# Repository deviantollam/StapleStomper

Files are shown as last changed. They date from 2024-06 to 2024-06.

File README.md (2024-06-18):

# Staple and Flag Tool

This tool was designed for ToorCamp to facilitate ShadyTel staff and other volunteers placing and removing landscaping staples and flags without throwing out their back!

## Features
- Magnetic Landscaping Staple Holder
  - Compatible with 2mm / 13 AWG / 14 AWG thickness, less than 32mm wide staples.
- Staple Removal Hook
- Landscaping Flag Holder (magnetic and friction fit)
- Landscaping Flag Removal Tool

## Changelog:

2024-06-18: Initial Release

## Bill of Materials:

- Approximately 20m of PETG filament
- 2x 6*10 mm round neodymium magnets 
- 3x 6*2 mm round neodymium magnets
- Cyanoacrylate glue or similar for setting magnets

- 1x 1/2" wooden dowel, cut to length
- 3 to 10 screws, depending on what you have on hand. 
  - #6 x 3/4" drywall screws preferred, M4 screws also compatible
  - (optional) a drill and drill bit to prevent the dowel from splitting
- (optional) Rubber Bands

## Print Instructions

### Staple Stomper

**Quantity Needed: 1**

The part should be oriented such that the hole for the dowel is pointed upwards / text is upright.

Supports are likely needed for under the circular feature for the dowel. I would recommend NOT adding supports into the magnet or staple holes unless you know you need them and can remove them cleanly.

Print in PETG, ASA, ABS, PC, or other material suited for impact resistance and direct sunlight at a minimum of 20% infill.

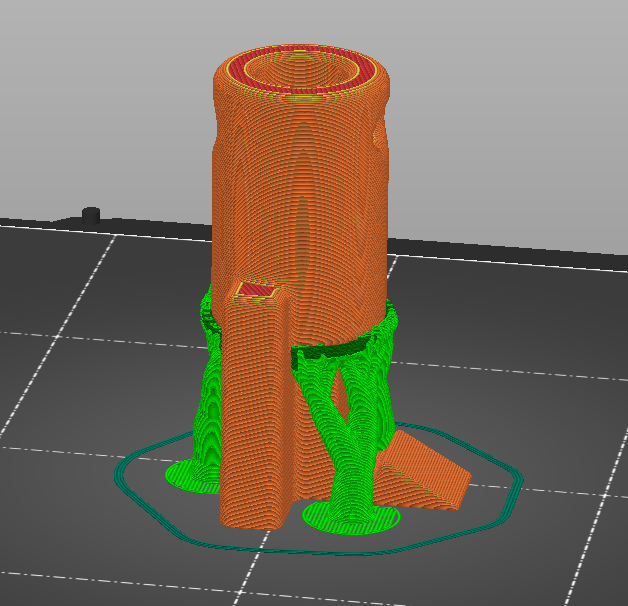
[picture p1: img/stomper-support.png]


### Flagpole Cap

**Quantity Needed: 1**

The part should be oriented so that it prints on its tallest axis. It will print better if the serrated feature faces up. No supports should be needed. 

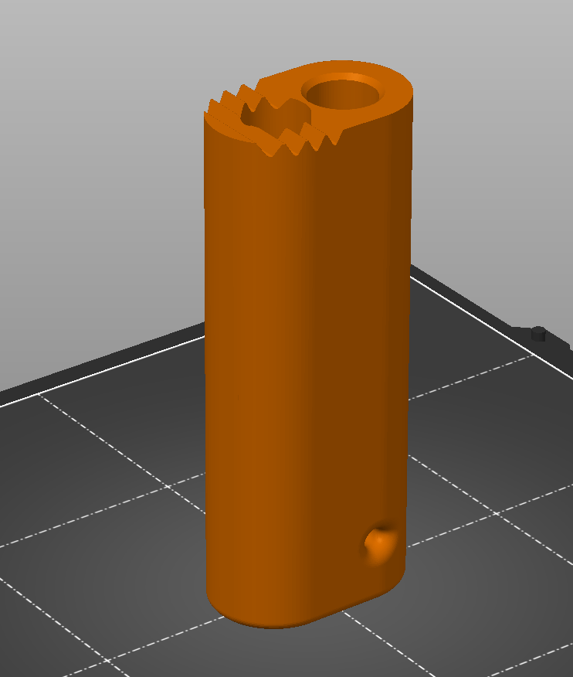
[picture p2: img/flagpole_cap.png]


Print in PETG, ASA, ABS, PC, or other material suited for impact resistance and direct sunlight at a minimum of 20% infill.

### Flagpole Guide

**Quantity Needed: 1 or 2**

The part should be oriented so that it prints on of the two flat faces. It will print better if the serrated feature faces up. No supports should be needed. 

Only 1 piece should be needed, but if you have especially long flags or if the soil is very hard, you may print an additional guide to help with flag placement.

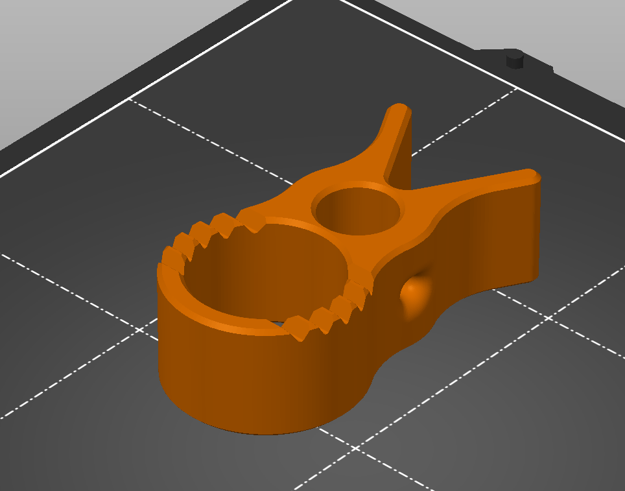
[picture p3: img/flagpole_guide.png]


Print in PETG, ASA, ABS, PC, or other material suited for impact resistance and direct sunlight at a minimum of 20% infill.

## Assembly Instructions

### Glue-Up

For the Staple Stomper, glue 1x 6 x 2mm magnet in the bottom for holding onto staples as you pull them from the ground.

Glue or place 1x 6 x 10 mm magnet in the dowel hole. When a dowel is installed, it will hold the magnet in if you do not wish to glue it.

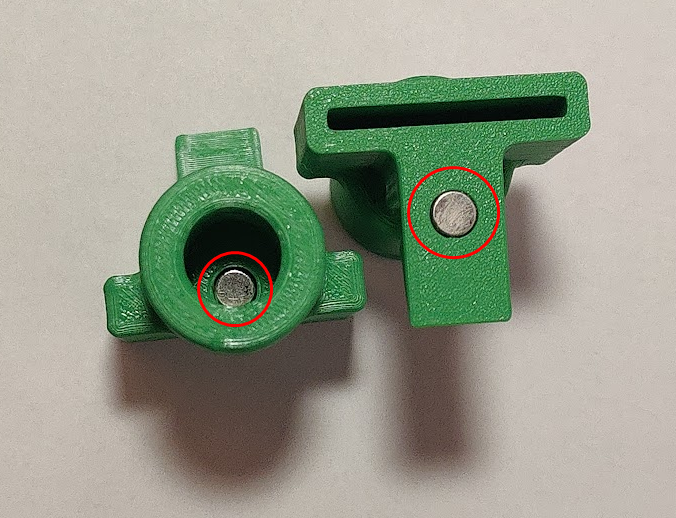
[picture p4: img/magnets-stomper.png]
img magnets


For the Flagpole Cap, glue 1x 6 x 10mm in the small diagonal hole on the top of the cap.

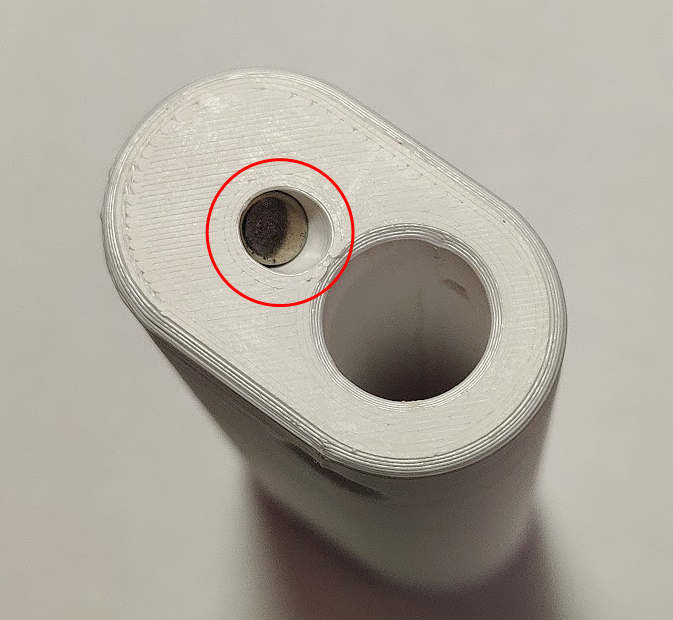
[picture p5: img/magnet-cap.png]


For the Flagpole Guide(s), glue 2x 6 x 2mm magnets in the two circular holes within the V. 

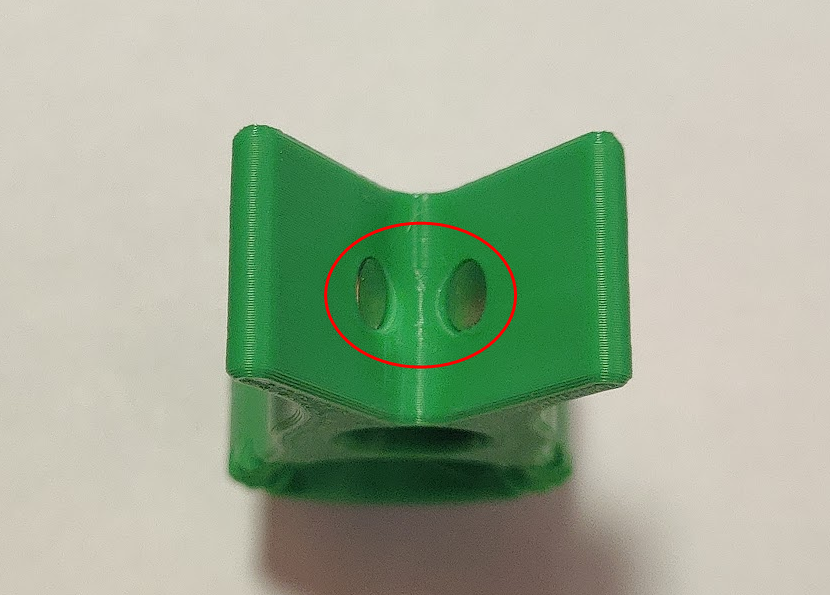
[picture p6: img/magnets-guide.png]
img magnets


### Screw-Up

1. Cut the dowel to a comfortable or convenient length for you.

2. Screw the Staple Stomper onto one end of the dowel. Pre-drill the hole if you need to. Don't forget to include the magnet if you wish to include it!

3. Insert a flag into the flag cap. Slide the flag cap on the other end of the dowel, such that the flag base points away from the staple end. Screw the flag cap into place such that 50-75mm (2-3") of the flag is extended past the dowel. This will be your insertion depth.

4. Screw the flagpole guide in at the base of the dowel, with the serrations facing the end of the dowel.

### Configuration

Landscaping flags, staples, and soil conditions will differ, so your mileage with this tool may vary. There are a few easy configuration mods that you could do to make it work better for you.

1. For the flagpole cap, you can add rubber bands in the serrations to decrease the diameter or add grip for the flag material.

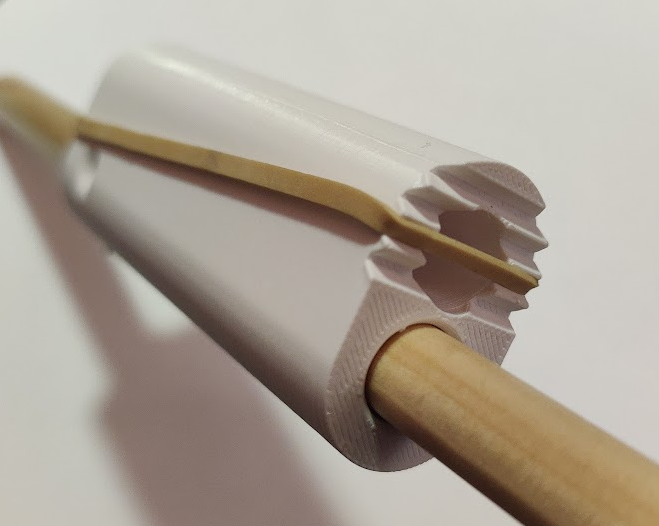
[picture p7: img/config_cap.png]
img config


2. The flagpole guide could be used in either orientation. You can line the circular hole, or the V guide up to flagpole cap. You can even print more than 1 guide if you find that your soil is especially tough to insert flags into. 

3. Just like the flagpole cap, you can also place rubber bands in the serrations on the flagpole guide. You may have to add a screw above the guide to anchor the rubber band if it is large. This can be used to reduce the diameter, but it also can provide a gripping force for you to grab the fabric of the flag with to pluck it out of the ground.

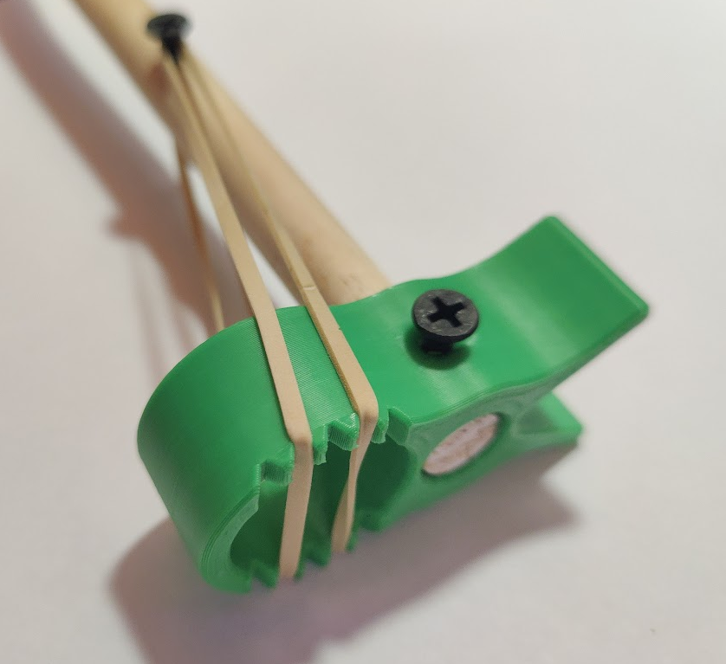
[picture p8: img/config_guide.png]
img config


"Thank you so much to MikeD for all of the amazing work translating an inintial rough sketch and notional concept into a brilliant and functional tool!  90% or more of the credit on this one goes to him, hands-down."  ~ Deviant Ollam

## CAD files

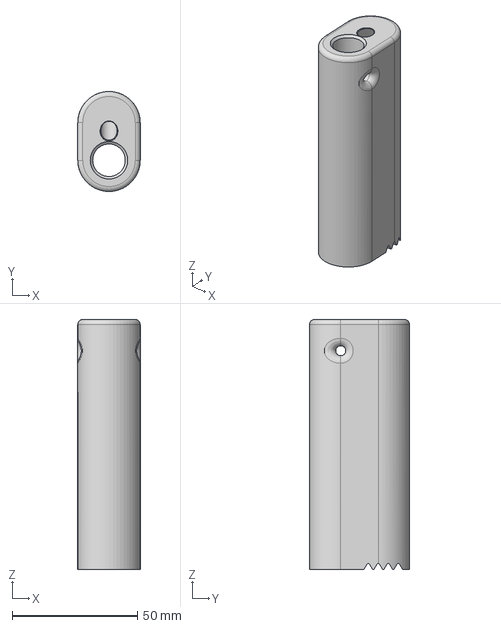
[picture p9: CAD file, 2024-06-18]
STEP/flagpole cap v4.step
25.0 x 40.0 x 100.0 mm

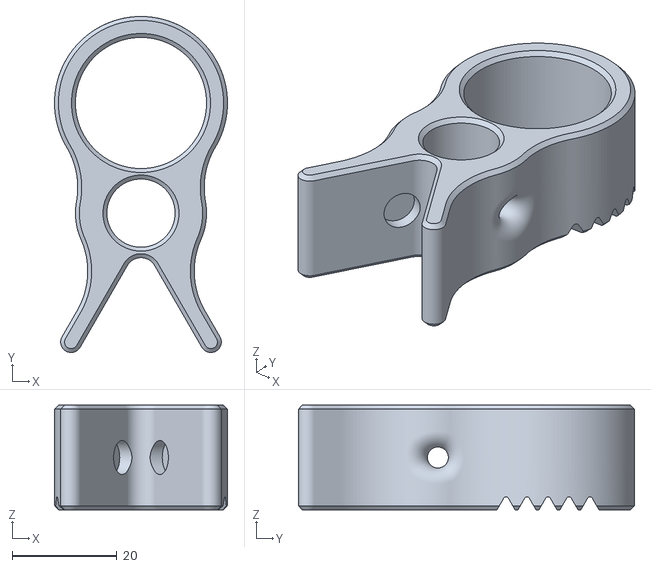
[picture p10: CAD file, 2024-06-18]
STL/flagpole guide v4.stl
33.0 x 64.1 x 20.0

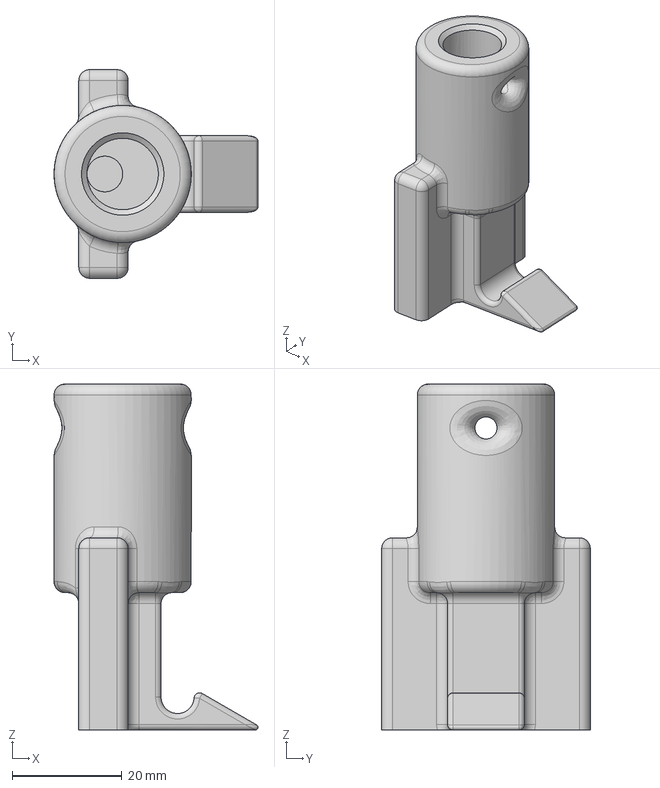
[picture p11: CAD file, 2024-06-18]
STEP/staple stomper v3.step
37.1 x 38.0 x 63.0 mm

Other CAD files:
STEP/flag guide v4.step
STL/flagpole cap v4.stl
STL/staple stomper v3.stl

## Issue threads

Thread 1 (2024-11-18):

Dangerously warps time and space

SkiffDank, 2024-11-18:
Was just picking up flags from a fiber dig and cleaning up the area of litter and debris the OSP crew left, the usual candy wrappers and chip bags, 9mm shell casings, condoms (unused/still in their pack) energy drink cans, and empty edible bags, and cable ties, when I found a bottle of cough syrup. Pondering why I do this for 100k a year I catch a glimpse of a half-full bottle and it didn't smell too greatly of urine. Roughly an hour later I'm back at the CO setting up my pillows for my afternoon nap. Having already been awake for 3 hours into my shift I'm not planning a chair nap, nooo sir, I'm starting to feel great like a dinner roll left on the edge of a hot soup bowl that isn't quite soggy, but definitely moist from the flavorful steam. I'm pulling a laydown no email and phone on silent kinda nap today boy. Pillows in each hand I lay them down and cut the loud ass AC units, figured 4 hour nap no more then a 20° rise of monitored temps and if anyone in the NOC catches it my phones not answering. Turned off all the overhead lights, leaving the flickering CRT monitor with no screensaver set running NT3 used to somehow interface with the SS7 gear as my perfect nightlight. Checked and made sure I had a pee bottle nearby. Feeling proud of myself for having accomplished my week's worth of work by 11am on Monday I felt like I really really deserved this nap and I was going to make the most of it. Well, nap i did! It must have been a twitchy nap however. I'd cozied up next to this giant northern telecom signaling server I like to lay next to but somehow my foot was tangled.. being quite unsure if I'd awoken in a new and different Kafkaesque dimension in which my legs and feet were now stringy branchy appendages like the Swamp Thing, I kicked, flailing about to either free my foot or test out this new mud and seaweed leg of mine. Abruptly the calming hum and warm air from the signaling server stopped. Its lights no longer flickering as it does whatever it normally does. Hopping on one real leg over to the light switch, I realized someone had somehow torn out the powerfeed from the back of this thing at some point during my nap. Carefully still one one leg I proceeded to examine the damage. Neutrals still there. I get the side dykes to strip some new copper from the torn wires. Getting everything back together and so far not having to call the 70yr old retired guy I inherited our SS7 department from, I get power! Yes! But no! It shuts right back off. I grab a flashlight and peek inside this cobwebby thing that's always "just ran" and flawlessly. Thank goodness, it's 30 years old with no manual and nothing but unmarked boxes of spare cards with no notes and one besides me responsible for. I check the wall breakers, good, but hmmm does this thing have fuses inside it? Reviewing my wiring job and seeing no leads touching too much I open it up. There ARE fuses in it! One is blown even! I frantically and still with one leg start going through drawers and cabinets that probably haven't been opened in decades. At last, success! I see one that may fit and not having a gum wrapper or a penny to stick in it I'm very relieved, if this thing dies everything moves over to Sigtran links and no more warm naps and days and weeks spent investigating and monitoring cryptic periodic SLT timer notifications that come in or dealing with yellow alarms carriers call in to report that always resolve themselves allowing me to spend my time doing actual stuff rather than working. No! This thing MUST be brought back to life! I have a sudden spike in confidence as I realize my leg has returned. I take my work slippers off and get shoes back on. I carefully remove the suspect glass fuse, not looking great and slightly covered with surface rust I carefully push the "new" fuse into place DANG I dropped it! Waaay down into this poor old thing, I shudder with horror as 1, my leg has become swampy again and 2, that's the only fuse I was able to find! Suddenly,  again, another moment of great luck! 1, my foot was just caught in an octal-cable and 2, I remembered I had my fantastic STAPLE STOMPER with me! The long protrusion thingy fit in through the filter panel and the magnet picked up my new rusty fuse just splendidly! Getting shocked putting it in once again initiated the swamp process for a few minutes but once I had my normal arms and legs back once again I was thrilled to see the dull incandescent green glow of the T1 cards coming to life and the steady hum of the 50 pin scsi drives spinning up! I win again! Not today nephilimic creatures that try to interfere with my legacy network, not today! The good and Godly prevail! I turn the AC back on, check some emails, send out a generic email to partner ILECS  "last-mile carrier sending framing and timing errors", I make a mental note to grumble about Brightspeed or Zayo next time I encounter anyone. Talking to yourself and grumbling is a great way to make people think you're busy working.  It's about 2pm, time to head home for the day and work remote the rest of the month. Anyway thank you for saving the day!

deviantollam, 2024-11-18:
Wow, i almost wasn't thinking i'd be able to read all that easily (my
eyes have challenges with lack of white space and paragraph breaks) but
I'm glad i made it through eventually... what a cool story and I'm so
glad to have been helpful!  😁👍

cheers and best of luck on your future projects, too!  best regards,

- dev

------ Original Message ------
From "SkiffDank" ***@***.***>
To "deviantollam/StapleStomper" ***@***.***>
Cc "Subscribed" ***@***.***>
Date 2024-11-17 20:59:55
Subject [deviantollam/StapleStomper] Dangerously warps time and space
(Issue #1)

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
